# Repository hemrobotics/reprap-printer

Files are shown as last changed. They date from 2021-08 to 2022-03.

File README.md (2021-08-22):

# reprap-printer
This repository contains configuration and design files related to our
RepRap 3D printer based on Prusa i3.

The printer at its dedicated location

Read the post [Building RepRap 3D
printer](https://geeksocket.in/posts/reprap-3d-printer/) for more
details about the first revision.

## Licensing
This repository is licensed under GNU General Public License v3.0. See
[LICENSE](./LICENSE) for the full license text.

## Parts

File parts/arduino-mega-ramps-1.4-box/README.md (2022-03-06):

# Arduino Mega + RAMPS 1.4 Case

Adapted from [Arduino Mega + RAMPS 1.4
Case](https://www.thingiverse.com/thing:1818162) by rockstorm.

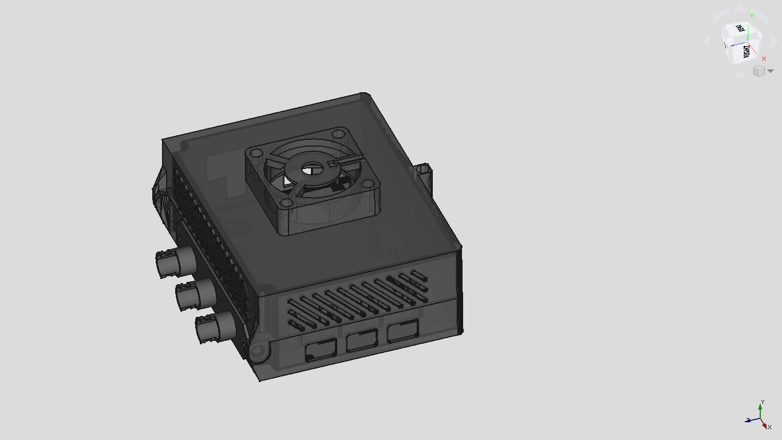
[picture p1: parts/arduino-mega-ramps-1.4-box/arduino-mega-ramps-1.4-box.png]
Rendering of the case with all parts


### Modifications
- Adds latch.
- Holes to mount the wire management plate.
- Support for 5015 fan.

Licensed under [Attribution-ShareAlike 4.0 International (CC BY-SA
4.0)](https://creativecommons.org/licenses/by-sa/4.0/).

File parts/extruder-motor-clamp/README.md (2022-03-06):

# Extruder motor clamp

These parts are used to clamp the extruder motor at the top of the
printer frame.

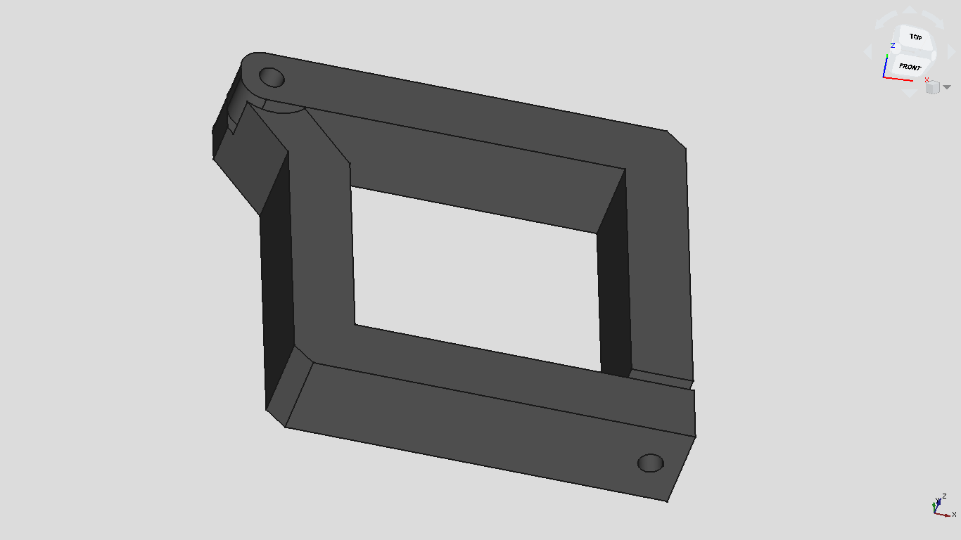
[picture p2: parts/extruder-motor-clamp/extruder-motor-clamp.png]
Rendering of the Extruder motor clamp parts


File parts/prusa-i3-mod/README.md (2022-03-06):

# Modified Prusa i3 MK3S parts

- [x-end-idler.scad](https://github.com/prusa3d/Original-Prusa-i3/blob/MK3S/Printed-Parts/SCAD/x-end-idler.scad)
- [y-belt-holder.stp](https://github.com/prusa3d/Original-Prusa-i3/blob/MK3S/Printed-Parts/STEP/y-belt-holder.stp)
- [y-belt-idler.stp](https://github.com/prusa3d/Original-Prusa-i3/blob/MK3S/Printed-Parts/STEP/y-belt-idler.stp)
- [y-belt-tensioner.stp](https://github.com/prusa3d/Original-Prusa-i3/blob/MK3S/Printed-Parts/STEP/y-belt-tensioner.stp)
- [y-rod-holder.stp](https://github.com/prusa3d/Original-Prusa-i3/blob/MK3S/Printed-Parts/STEP/y-rod-holder.stp)

### Modifications
- Adds holes for rod adjustments (x-end-idler).
- Increases the height.
- Adds extra hole at the bottom (y-belt-idler).

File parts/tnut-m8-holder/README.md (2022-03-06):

# T-nut M8 holder

Holder to convert normal M8 nut into a T-nut suitable to use with
Prusa i3's X axis parts (Prusa i3 uses TR-nut).

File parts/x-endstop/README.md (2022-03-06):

# X endstop

Adapted from [Prusa i3 / P3Steel Improved Endstop Holders
Collection](https://www.thingiverse.com/thing:612028) by AndrewBCN.

### Modifications
- Adds a slot for the belt.

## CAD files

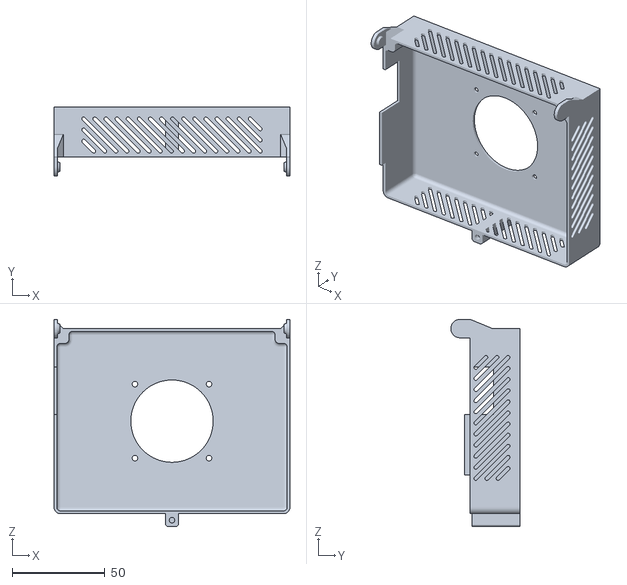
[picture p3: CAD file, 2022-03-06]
parts/arduino-mega-ramps-1.4-box/box-lid.stl
127.5 x 37.5 x 112.0

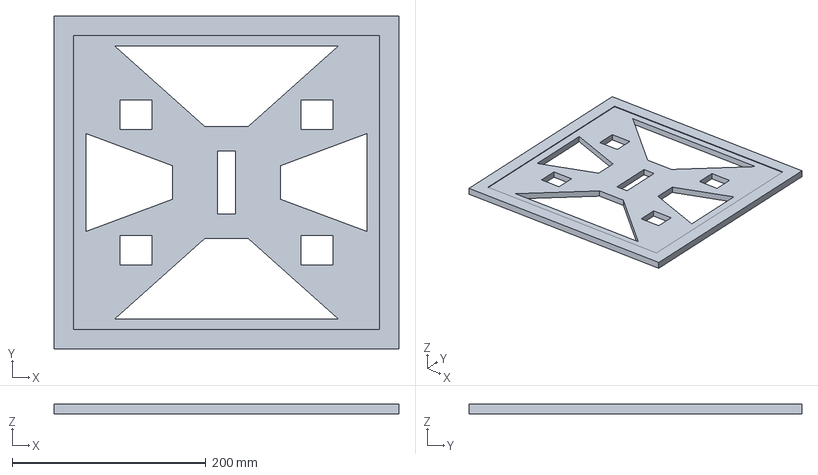
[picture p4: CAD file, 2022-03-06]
parts/bed-base/bed-base.FCStd
356.0 x 344.0 x 10.0 mm

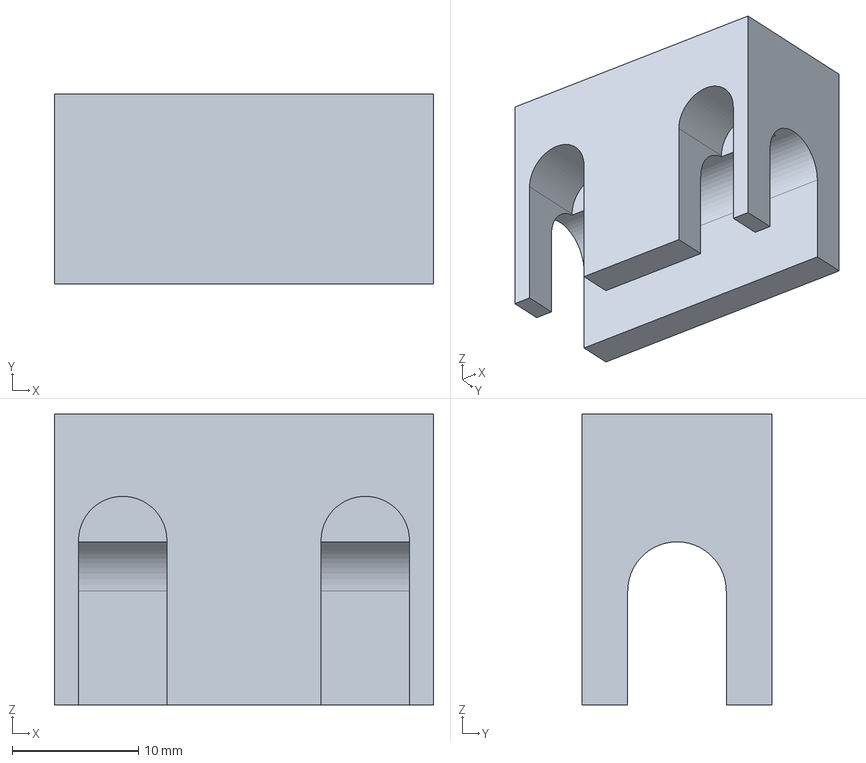
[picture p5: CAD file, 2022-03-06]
parts/extruder-motor-clamp/extruder-motor-clamp-base.FCStd
30.0 x 15.0 x 23.0 mm

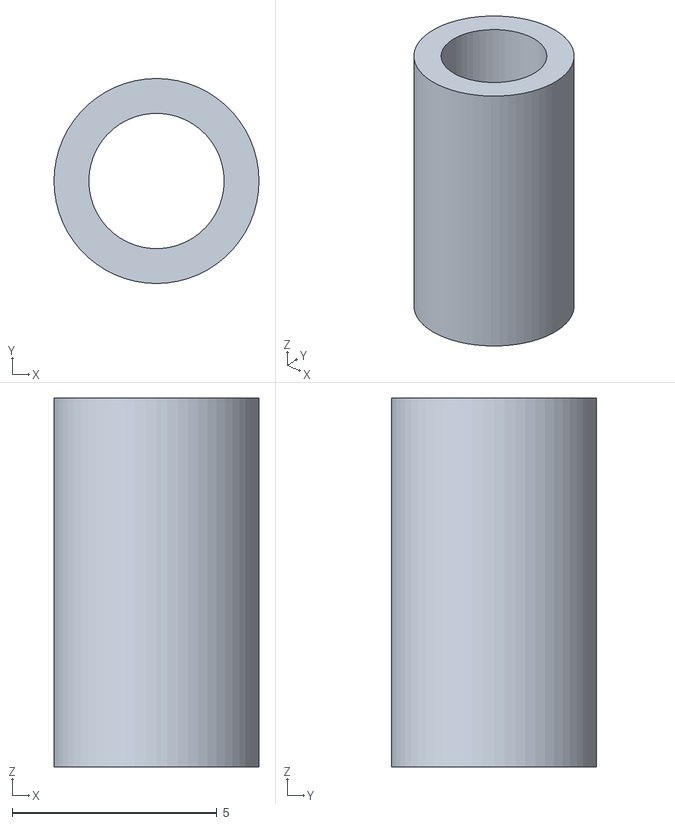
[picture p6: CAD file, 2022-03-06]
parts/hole-pad/gt2-pulley-hole-pad.stl
5.00 x 5.00 x 9.00

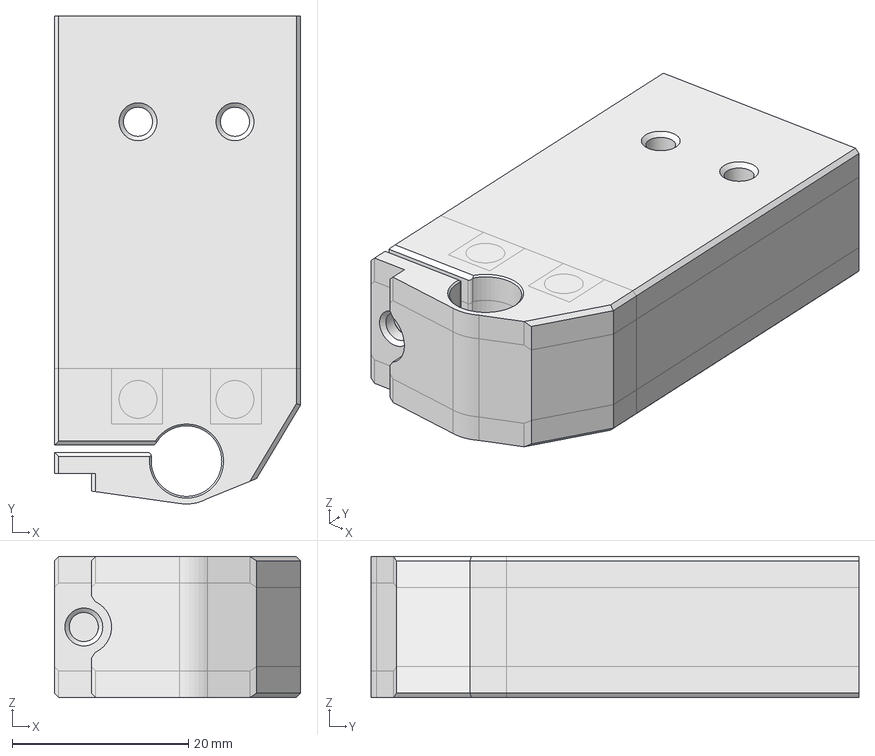
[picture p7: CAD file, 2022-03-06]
parts/prusa-i3-mod/y-rod-holder.FCStd
28.0 x 55.4 x 16.0 mm

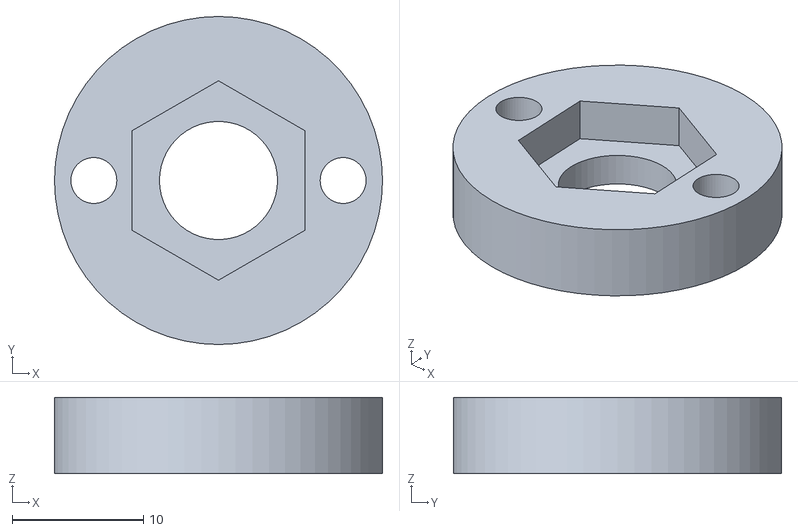
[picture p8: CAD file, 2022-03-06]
parts/tnut-m8-holder/tnut-m8-holder-top.stl
25.0 x 25.0 x 5.80

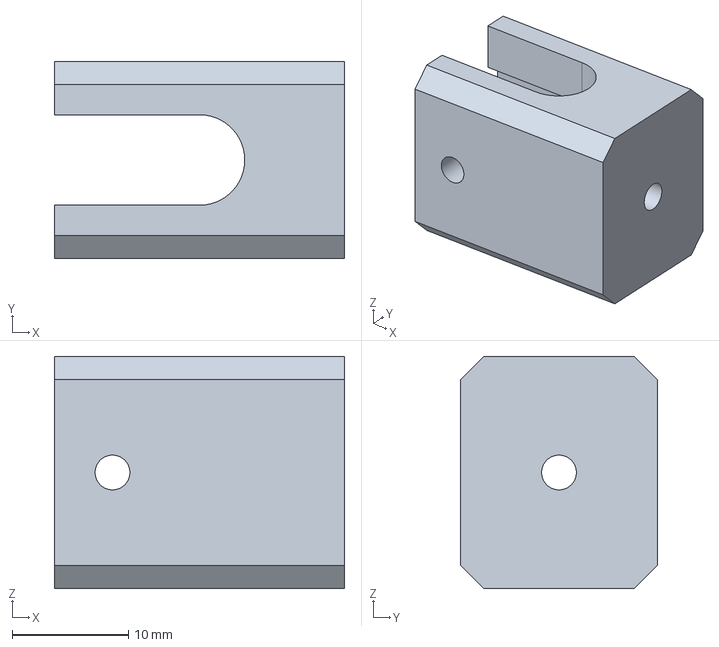
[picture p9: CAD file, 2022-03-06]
parts/x-carriage-wire-holder/x-carriage-wire-holder-base.FCStd
25.0 x 17.0 x 20.0 mm

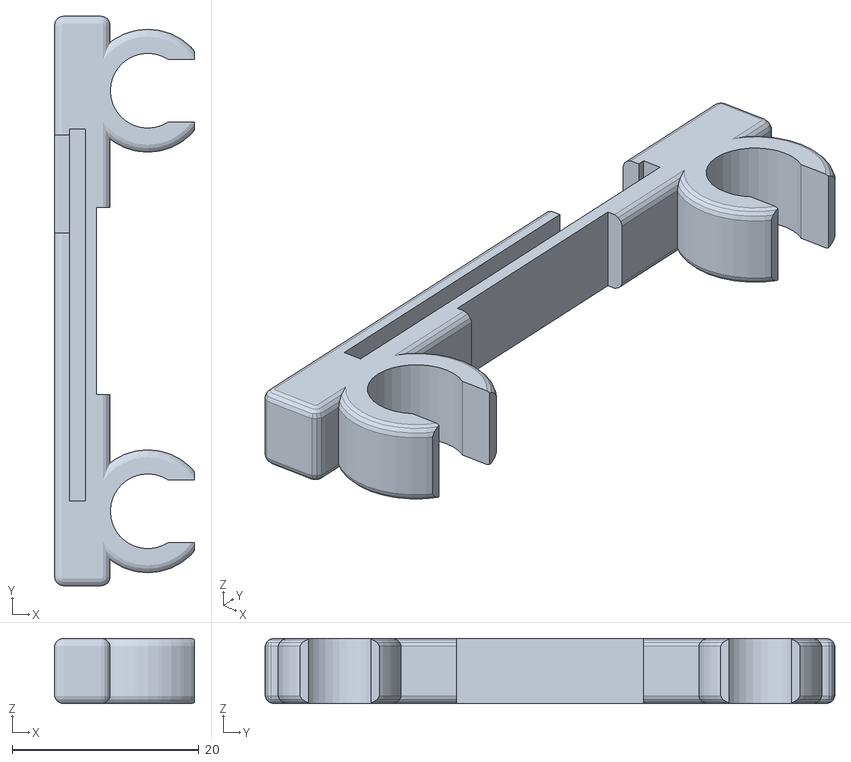
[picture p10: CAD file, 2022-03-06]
parts/x-endstop/Prusa_i3_X-axis_endstop_holder.stl
15.0 x 61.0 x 6.96

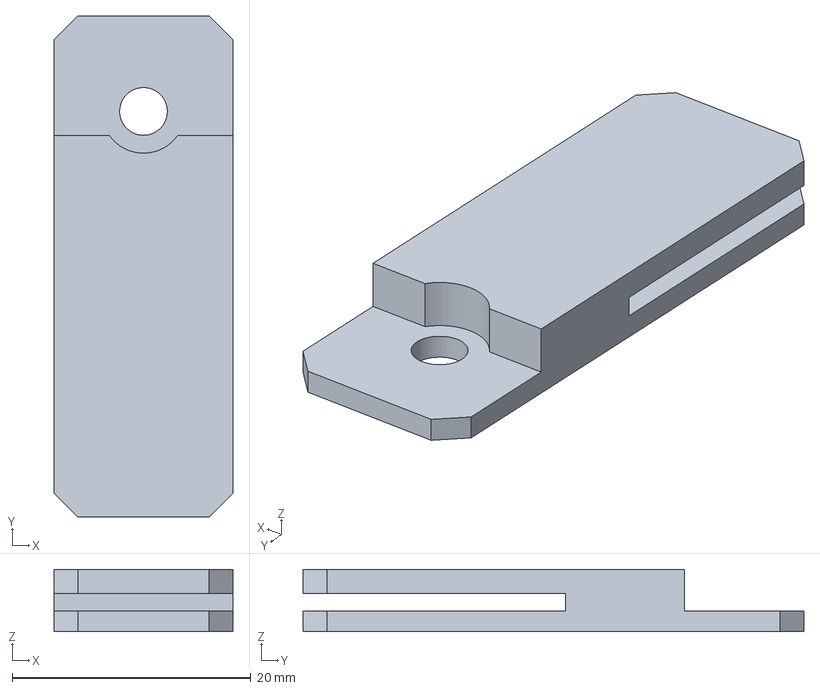
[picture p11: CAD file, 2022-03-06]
parts/y-endstop/y-endstop.FCStd
15.0 x 42.0 x 5.20 mm

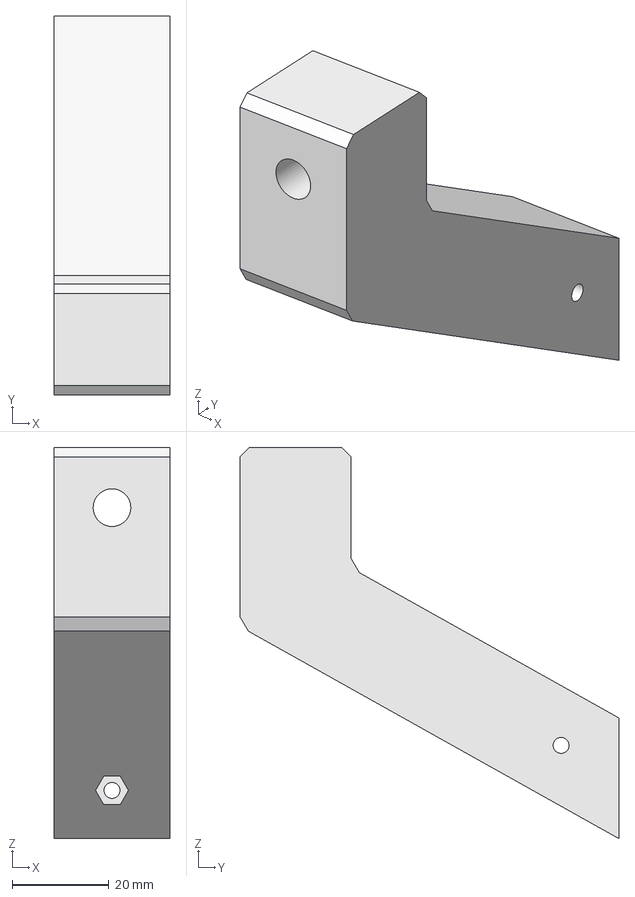
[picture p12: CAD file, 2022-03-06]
parts/z-beam-support/z-beam-support.FCStd
24.0 x 78.5 x 81.1 mm

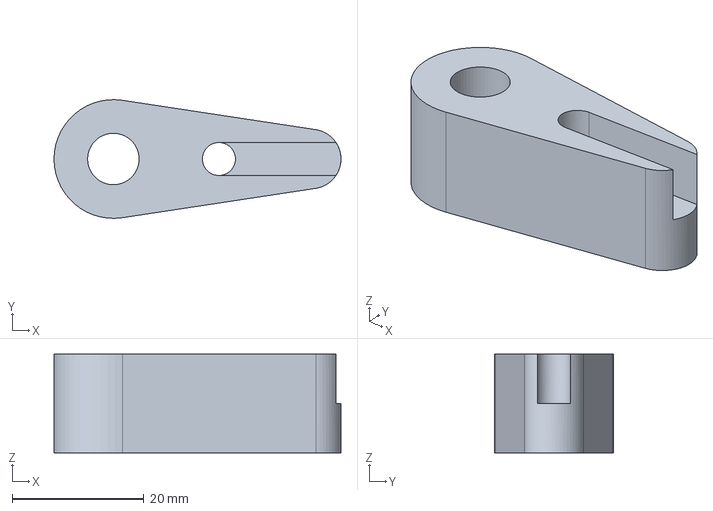
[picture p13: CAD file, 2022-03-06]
parts/z-side-support/z-side-support-top.FCStd
43.5 x 18.0 x 15.0 mm

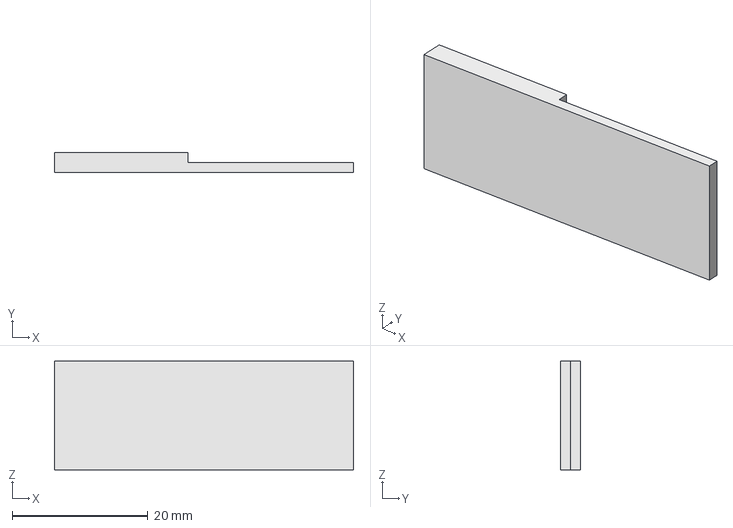
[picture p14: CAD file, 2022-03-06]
parts/z-support/z-support-top.FCStd
44.0 x 3.00 x 16.0 mm

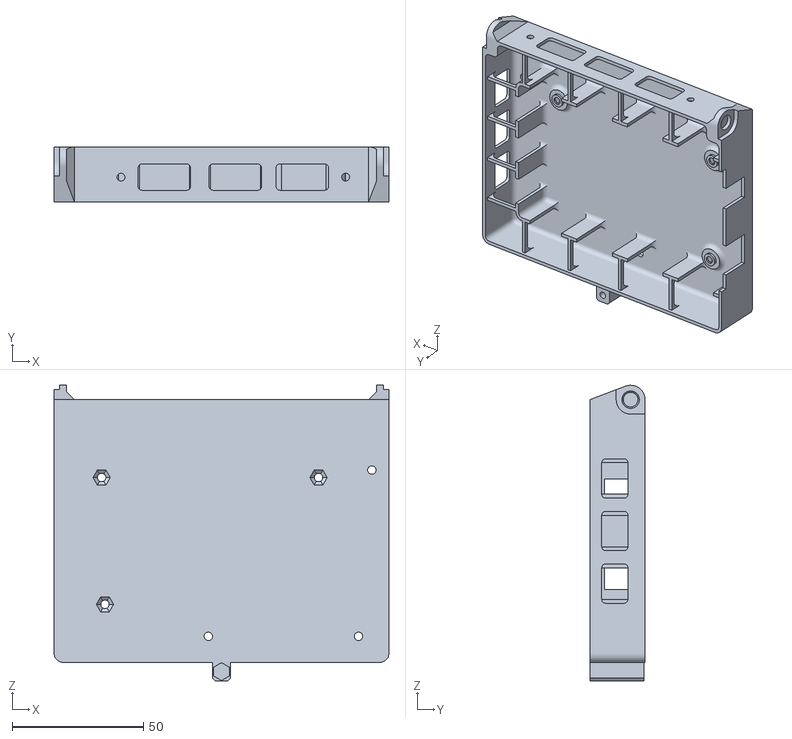
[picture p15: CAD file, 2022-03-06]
parts/arduino-mega-ramps-1.4-box/box-base.stl
127.5 x 21.0 x 112.5

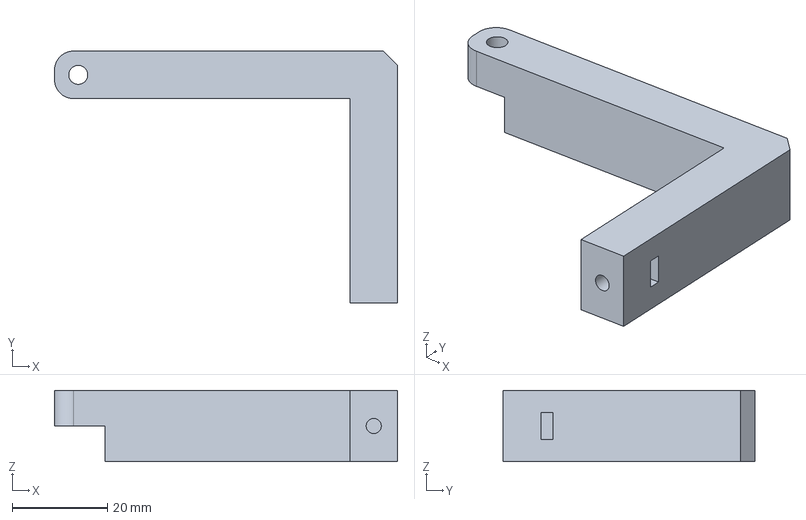
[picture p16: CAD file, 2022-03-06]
parts/extruder-motor-clamp/extruder-motor-clamp-back.FCStd
72.2 x 53.0 x 15.0 mm

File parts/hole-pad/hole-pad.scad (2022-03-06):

// Copyright (C) 2022  Bhavin Gandhi
//
// This program is free software: you can redistribute it and/or modify
// it under the terms of the GNU General Public License as published by
// the Free Software Foundation, either version 3 of the License, or
// (at your option) any later version.
//
// This program is distributed in the hope that it will be useful,
// but WITHOUT ANY WARRANTY; without even the implied warranty of
// MERCHANTABILITY or FITNESS FOR A PARTICULAR PURPOSE.  See the
// GNU General Public License for more details.
//
// You should have received a copy of the GNU General Public License
// along with this program.  If not, see <https://www.gnu.org/licenses/>.

module hole_pad(height, radius) {
    difference()
    {
        cylinder(h = height, r = radius, $fn = 60);

        // M3 bolt hole
        translate(v = [0, 0, -1]) cylinder(h = height+2, r = 1.65, $fn = 50);
    }
}

// For 606-2RS bearing
// Bearing width is actually 6mm but we are using
// it at places where we have space of 9.4+mm
// hole_pad(8.5, 3);

// For GT2 20 teeth idler pulley
hole_pad(9, 2.5);

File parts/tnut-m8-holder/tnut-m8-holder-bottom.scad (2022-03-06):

// Bottom part of the holder

use <tnut-m8-holder.scad>

tnut_m8_holder(1.5, false);

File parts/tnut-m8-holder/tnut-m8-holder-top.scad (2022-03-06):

// Top part of the holder

use <tnut-m8-holder.scad>

tnut_m8_holder(2.5, true);

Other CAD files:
parts/prusa-i3-mod/y-belt-holder.FCStd
parts/tnut-m8-holder/tnut-m8-holder-bottom.stl
parts/x-carriage-wire-holder/x-carriage-wire-holder-ring.FCStd
parts/y-endstop/y-endstop-plug.FCStd
parts/tnut-m8-holder/tnut-m8-holder.scad
parts/arduino-mega-ramps-1.4-box/wire-management-plate.FCStd
parts/arduino-mega-ramps-1.4-box/wire-management-plate.stl
parts/extruder-motor-clamp/extruder-motor-clamp-back.stl
parts/extruder-motor-clamp/extruder-motor-clamp-base.stl
parts/extruder-motor-clamp/extruder-motor-clamp-front.FCStd
parts/extruder-motor-clamp/extruder-motor-clamp-front.stl
parts/prusa-i3-mod/x-end-idler.FCStd
parts/prusa-i3-mod/x-end-idler.stl
parts/prusa-i3-mod/y-belt-holder.stl
parts/prusa-i3-mod/y-belt-idler.FCStd
parts/prusa-i3-mod/y-belt-idler.stl
parts/prusa-i3-mod/y-belt-tensioner.FCStd
parts/prusa-i3-mod/y-belt-tensioner.stl
parts/prusa-i3-mod/y-rod-holder.stl
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

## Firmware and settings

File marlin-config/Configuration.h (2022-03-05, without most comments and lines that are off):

#pragma once
#define CONFIGURATION_H_VERSION 020007
#define STRING_CONFIG_H_AUTHOR "(none, default config)" // Who made the changes.
#define SHOW_BOOTSCREEN
#define SERIAL_PORT 0
#define BAUDRATE 250000
  #define MOTHERBOARD BOARD_RAMPS_14_EFF
#define EXTRUDERS 1
#define DEFAULT_NOMINAL_FILAMENT_DIA 1.75
#define TEMP_SENSOR_0 5
#define TEMP_SENSOR_1 0
#define TEMP_SENSOR_2 0
#define TEMP_SENSOR_3 0
#define TEMP_SENSOR_4 0
#define TEMP_SENSOR_5 0
#define TEMP_SENSOR_6 0
#define TEMP_SENSOR_7 0
#define TEMP_SENSOR_BED 0
#define TEMP_SENSOR_PROBE 0
#define TEMP_SENSOR_CHAMBER 0
#define DUMMY_THERMISTOR_998_VALUE 25
#define DUMMY_THERMISTOR_999_VALUE 100
#define MAX_REDUNDANT_TEMP_SENSOR_DIFF 10
#define TEMP_RESIDENCY_TIME     10  // (seconds) Time to wait for hotend to "settle" in M109
#define TEMP_WINDOW              1  // (°C) Temperature proximity for the "temperature reached" timer
#define TEMP_HYSTERESIS          3  // (°C) Temperature proximity considered "close enough" to the target
#define TEMP_BED_RESIDENCY_TIME 10  // (seconds) Time to wait for bed to "settle" in M190
#define TEMP_BED_WINDOW          1  // (°C) Temperature proximity for the "temperature reached" timer
#define TEMP_BED_HYSTERESIS      3  // (°C) Temperature proximity considered "close enough" to the target
#define HEATER_0_MINTEMP   5
#define HEATER_1_MINTEMP   5
#define HEATER_2_MINTEMP   5
#define HEATER_3_MINTEMP   5
#define HEATER_4_MINTEMP   5
#define HEATER_5_MINTEMP   5
#define HEATER_6_MINTEMP   5
#define HEATER_7_MINTEMP   5
#define BED_MINTEMP        5
#define HEATER_0_MAXTEMP 260
#define HEATER_1_MAXTEMP 275
#define HEATER_2_MAXTEMP 275
#define HEATER_3_MAXTEMP 275
#define HEATER_4_MAXTEMP 275
#define HEATER_5_MAXTEMP 275
#define HEATER_6_MAXTEMP 275
#define HEATER_7_MAXTEMP 275
#define BED_MAXTEMP      120
#define PIDTEMP
#define BANG_MAX 255     // Limits current to nozzle while in bang-bang mode; 255=full current
#define PID_MAX BANG_MAX // Limits current to nozzle while PID is active (see PID_FUNCTIONAL_RANGE below); 255=full current
#define PID_K1 0.95      // Smoothing factor within any PID loop
    #define DEFAULT_Kp  46.45
    #define DEFAULT_Ki   4.76
    #define DEFAULT_Kd 113.20
#define MAX_BED_POWER 255 // limits duty cycle to bed; 255=full current
  #define PID_FUNCTIONAL_RANGE 10 // If the temperature difference between the target temperature and the actual temperature
#define PREVENT_COLD_EXTRUSION
#define EXTRUDE_MINTEMP 170
#define PREVENT_LENGTHY_EXTRUDE
#define EXTRUDE_MAXLENGTH 200
#define THERMAL_PROTECTION_HOTENDS // Enable thermal protection for all extruders
#define THERMAL_PROTECTION_BED     // Enable thermal protection for the heated bed
#define THERMAL_PROTECTION_CHAMBER // Enable thermal protection for the heated chamber
#define USE_XMIN_PLUG
#define USE_YMIN_PLUG
#define USE_ZMIN_PLUG
#define ENDSTOPPULLUPS
#define X_MIN_ENDSTOP_INVERTING false // Set to true to invert the logic of the endstop.
#define Y_MIN_ENDSTOP_INVERTING false // Set to true to invert the logic of the endstop.
#define Z_MIN_ENDSTOP_INVERTING true  // Set to true to invert the logic of the endstop.
#define X_MAX_ENDSTOP_INVERTING false // Set to true to invert the logic of the endstop.
#define Y_MAX_ENDSTOP_INVERTING false // Set to true to invert the logic of the endstop.
#define Z_MAX_ENDSTOP_INVERTING false // Set to true to invert the logic of the endstop.
#define Z_MIN_PROBE_ENDSTOP_INVERTING true // Set to true to invert the logic of the probe.
#define Z2_DRIVER_TYPE A4988
#define DEFAULT_AXIS_STEPS_PER_UNIT   { 100, 80, 2560, 95 }
#define DEFAULT_MAX_FEEDRATE          { 200, 200, 2.25, 25 }
#define DEFAULT_MAX_ACCELERATION      { 1000, 1000, 100, 10000 }
#define DEFAULT_ACCELERATION          500    // X, Y, Z and E acceleration for printing moves
#define DEFAULT_RETRACT_ACCELERATION  500    // E acceleration for retracts
#define DEFAULT_TRAVEL_ACCELERATION   500    // X, Y, Z acceleration for travel (non printing) moves
#define DEFAULT_EJERK    5.0  // May be used by Linear Advance
  #define JUNCTION_DEVIATION_MM 0.013 // (mm) Distance from real junction edge
  #define JD_HANDLE_SMALL_SEGMENTS    // Use curvature estimation instead of just the junction angle
#define S_CURVE_ACCELERATION
#define Z_MIN_PROBE_USES_Z_MIN_ENDSTOP_PIN
#define FIX_MOUNTED_PROBE
#define NOZZLE_TO_PROBE_OFFSET { 32.5, 5, -5.73 }
#define PROBING_MARGIN 10
#define XY_PROBE_SPEED (133*60)
#define Z_PROBE_SPEED_FAST HOMING_FEEDRATE_Z
#define Z_PROBE_SPEED_SLOW (Z_PROBE_SPEED_FAST / 2)
#define MULTIPLE_PROBING 2
#define Z_CLEARANCE_DEPLOY_PROBE   10 // Z Clearance for Deploy/Stow
#define Z_CLEARANCE_BETWEEN_PROBES  5 // Z Clearance between probe points
#define Z_CLEARANCE_MULTI_PROBE     5 // Z Clearance between multiple probes
#define Z_PROBE_LOW_POINT          -2 // Farthest distance below the trigger-point to go before stopping
#define Z_PROBE_OFFSET_RANGE_MIN -20
#define Z_PROBE_OFFSET_RANGE_MAX 20
#define X_ENABLE_ON 0
#define Y_ENABLE_ON 0
#define Z_ENABLE_ON 0
#define E_ENABLE_ON 0 // For all extruders
#define DISABLE_X false
#define DISABLE_Y false
#define DISABLE_Z false
#define DISABLE_E false             // Disable the extruder when not stepping
#define DISABLE_INACTIVE_EXTRUDER   // Keep only the active extruder enabled
#define INVERT_X_DIR false
#define INVERT_Y_DIR true
#define INVERT_Z_DIR false
#define INVERT_E0_DIR false
#define INVERT_E1_DIR false
#define INVERT_E2_DIR false
#define INVERT_E3_DIR false
#define INVERT_E4_DIR false
#define INVERT_E5_DIR false
#define INVERT_E6_DIR false
#define INVERT_E7_DIR false
#define X_HOME_DIR -1
#define Y_HOME_DIR -1
#define Z_HOME_DIR -1
#define X_BED_SIZE 270
#define Y_BED_SIZE 270
#define X_MIN_POS 0
#define Y_MIN_POS 0
#define Z_MIN_POS 0
#define X_MAX_POS X_BED_SIZE
#define Y_MAX_POS Y_BED_SIZE
#define Z_MAX_POS 200
#define MIN_SOFTWARE_ENDSTOPS
  #define MIN_SOFTWARE_ENDSTOP_X
  #define MIN_SOFTWARE_ENDSTOP_Y
  #define MIN_SOFTWARE_ENDSTOP_Z
#define MAX_SOFTWARE_ENDSTOPS
  #define MAX_SOFTWARE_ENDSTOP_X
  #define MAX_SOFTWARE_ENDSTOP_Y
  #define MAX_SOFTWARE_ENDSTOP_Z
#define AUTO_BED_LEVELING_BILINEAR
  #define ENABLE_LEVELING_FADE_HEIGHT
  #define SEGMENT_LEVELED_MOVES
  #define LEVELED_SEGMENT_LENGTH 5.0 // (mm) Length of all segments (except the last one)
  #define GRID_MAX_POINTS_X 4
  #define GRID_MAX_POINTS_Y GRID_MAX_POINTS_X
#define Z_SAFE_HOMING
  #define Z_SAFE_HOMING_X_POINT X_CENTER  // X point for Z homing
  #define Z_SAFE_HOMING_Y_POINT Y_CENTER  // Y point for Z homing
#define HOMING_FEEDRATE_XY (50*60)
#define HOMING_FEEDRATE_Z  (4*60)
#define VALIDATE_HOMING_ENDSTOPS
#define SKEW_CORRECTION
  #define XY_DIAG_AC 140.1
  #define XY_DIAG_BD 142.1
  #define XY_SIDE_AD 99.98
  #define SKEW_CORRECTION_GCODE
#define EEPROM_CHITCHAT       // Give feedback on EEPROM commands. Disable to save PROGMEM.
#define EEPROM_BOOT_SILENT    // Keep M503 quiet and only give errors during first load
#define HOST_KEEPALIVE_FEATURE        // Disable this if your host doesn't like keepalive messages
#define DEFAULT_KEEPALIVE_INTERVAL 2  // Number of seconds between "busy" messages. Set with M113.
#define BUSY_WHILE_HEATING            // Some hosts require "busy" messages even during heating
#define PREHEAT_1_LABEL       "PLA"
#define PREHEAT_1_TEMP_HOTEND 180
#define PREHEAT_1_TEMP_BED     70
#define PREHEAT_1_FAN_SPEED     0 // Value from 0 to 255
#define PREHEAT_2_LABEL       "ABS"
#define PREHEAT_2_TEMP_HOTEND 240
#define PREHEAT_2_TEMP_BED    110
#define PREHEAT_2_FAN_SPEED     0 // Value from 0 to 255
#define PRINTJOB_TIMER_AUTOSTART
#define LCD_LANGUAGE en
#define DISPLAY_CHARSET_HD44780 JAPANESE
#define LCD_INFO_SCREEN_STYLE 0
#define SOFT_PWM_SCALE 0
#define SERVO_DELAY { 300 }

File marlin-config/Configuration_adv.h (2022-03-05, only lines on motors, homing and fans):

#define E0_AUTO_FAN_PIN FAN1_PIN
#define E1_AUTO_FAN_PIN -1
#define E2_AUTO_FAN_PIN -1
#define E3_AUTO_FAN_PIN -1
#define E4_AUTO_FAN_PIN -1
#define E5_AUTO_FAN_PIN -1
#define E6_AUTO_FAN_PIN -1
#define E7_AUTO_FAN_PIN -1
#define CHAMBER_AUTO_FAN_PIN -1
#define HOMING_BUMP_MM      { 5, 5, 2 }       // (mm) Backoff from endstops after first bump
#define HOMING_BUMP_DIVISOR { 2, 2, 4 }       // Re-Bump Speed Divisor (Divides the Homing Feedrate)
#define MICROSTEP_MODES { 16, 16, 16, 16, 16, 16 } // [1,2,4,8,16]

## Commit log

2021-07-31 config: initial configuration import from Marlin
    Commit: 3e1b9e11d73fab93e44ede6768d0c51638e6bced
    [Configuration.h, Configuration_adv.h]
2021-07-31 config: maximum temperature modifications
    Based on https://youtu.be/3gwWVFtdg-4
    [Configuration.h]
2021-07-31 config: set the temperature sensor type to 5
    - https://www.3djake.com/e3d/100k-ohm-ntc-thermistor-semitec
    - https://robu.in/?s=422131&post_type=product
    [Configuration.h]
2021-07-31 config: decrease the max feedrate for Z axis motors
    These motor were making noise and skipping steps while homing.
    https://marlinfw.org/docs/configuration/configuration.html#default-max-feed-rate--
    [Configuration.h]
2021-07-31 config: set the default steps/mm
    - https://blog.prusaprinters.org/calculator_3416/
    - https://reprap.org/wiki/Triffid_Hunter%27s_Calibration_Guide#Measure
    [Configuration.h]
2021-07-31 config: X axis motor is at right side along with the endstop
    Basically the homing happens to the MAX side.
    [Configuration.h]
2021-07-31 config: using two separate stepper motor drivers for two Z axis
    Uses the E1 from RAMPS as Z2. Also enabled corresponding stepper driver.
    https://marlinfw.org/docs/configuration/configuration.html#dual-steppers-/-dual-endstops
    [Configuration.h, Configuration_adv.h]
2021-07-31 config: set correct bed dimensions based on the glass position
    As the motor is on right side, the X maximum is based on the actual
    bed size. That way the X0 comes correctly on the glass. The actual
    printing area is kept limited to the glass with the help of slicer.
    When the bed reaches the Y endstop, nozzle is not on the glass (it is
    even not on the bed, it is in the air). Setting the Y_MIN_POS to a
    correct negative value, so that Y0 comes correctly on the glass.
    https://www.reprap.org/wiki/Configuring_Marlin_Bed_Dimensions
    [Configuration.h]
2021-07-31 config: use RAMPS Extruder Fan Fan setup
    RAMPS_D9_PIN: FAN_PIN (part cooling fan)
    RAMPS_D8_PIN: FAN1_PIN (extruder / hot end fan), set as auto fan pin
    to turn on the fan when hot end reaches 50°C.
    https://github.com/MarlinFirmware/Marlin/issues/3234#issuecomment-201110671
    https://github.com/MarlinFirmware/Marlin/issues/4579#issuecomment-243572261
    https://www.youtube.com/watch?v=0W3VQpL0e8g
    [Configuration.h, Configuration_adv.h]
2021-07-31 config: decrease the overall acceleration
    Printer needs to move a lot slower than what it is configured right
    now.
    The values are taken from Ender 3's configuration:
    https://github.com/MarlinFirmware/Configurations/blob/628a24b282a304b223b8d26fe7937b8d44a791b2/config/examples/Creality/Ender-3/BigTreeTech%20E3%20RRF/Configuration.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
    [Configuration.h]
2022-03-02 config: old bed on reversion 2
    [Configuration.h]
2022-03-02 config: using 16 teeth pulley on X axis
    [Configuration.h]
2022-03-05 config: X axis motor is on the left now
    [Configuration.h]
2022-03-05 config: set the CRC sheet + MDF bed size
    [Configuration.h]
2022-03-05 config: enable Z probe and bed leveling
    [Configuration.h]
2022-03-05 config: set PID autotuning values
    Ref: https://github.com/MarlinFirmware/Configurations/blob/1c8e649/config/examples/Anet/A8/Configuration.h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
    [Configuration.h]
2022-03-05 config: tweak the thermal protection values
    Ref: https://github.com/MarlinFirmware/Configurations/blob/a448faa/config/examples/Anet/A8/Configuration_adv.h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
    [Configuration_adv.h]
2022-03-05 config: experimented values of E steps/mm and X, Y feedrate
    [Configuration.h]
2022-03-05 config: enable skew compensation
    [Configuration.h]
2022-03-06 parts: add parts of the second revision
    [Prusa_i3_X-axis_endstop_holder.scad, Prusa_i3_X-axis_endstop_holder.stl, bed-base.FCStd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]

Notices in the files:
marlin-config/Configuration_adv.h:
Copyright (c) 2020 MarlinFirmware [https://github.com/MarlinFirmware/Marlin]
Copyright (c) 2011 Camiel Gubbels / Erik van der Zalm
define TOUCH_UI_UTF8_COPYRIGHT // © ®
